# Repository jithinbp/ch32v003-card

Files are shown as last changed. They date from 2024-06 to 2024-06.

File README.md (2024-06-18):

# CH32V003 based Wedding Invites

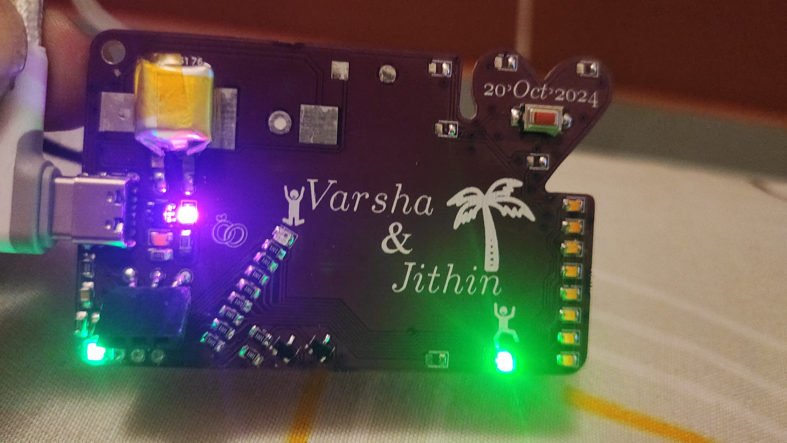
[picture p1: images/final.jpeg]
Screencast

Screencast display!

Schematics originally based on [Christmas LED ball](https://www.hackster.io/fabiosouza/christmas-ornament-based-on-ch32v003-riscv-mcu-2793db) .

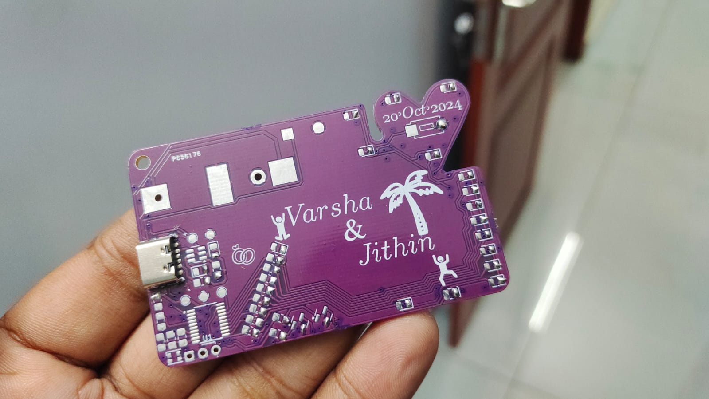
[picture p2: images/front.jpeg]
Front Render

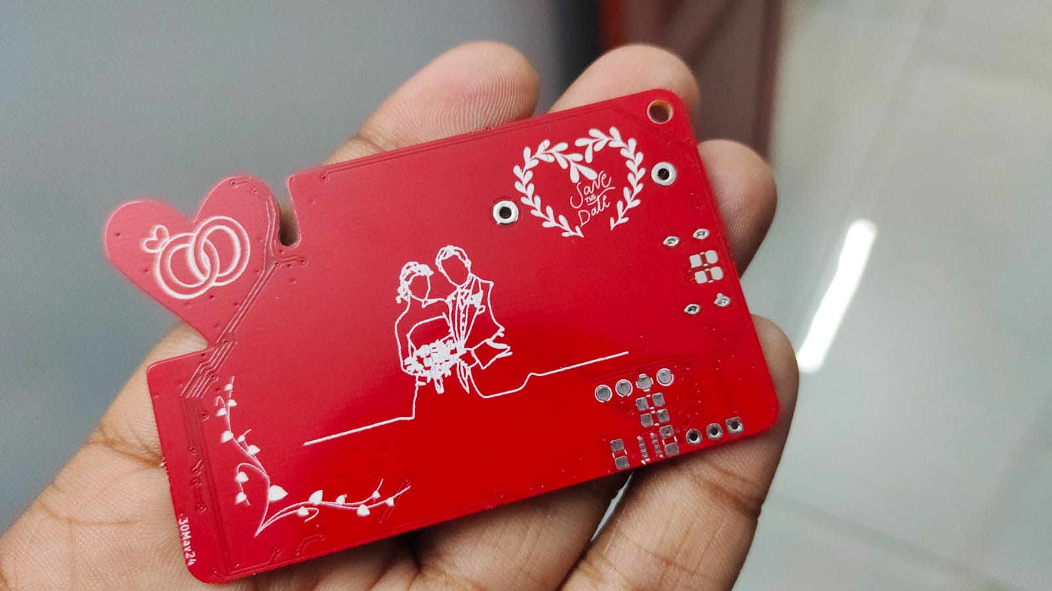
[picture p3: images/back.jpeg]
Back Render


## Features

+ USB C 6 pin connector with TP4057 for charging
+ 3.7V battery
+ CH32V003 processor
+ 14 LEDs
+ 1 RGB LED
+ IR Receiver
+ Reed switch for timing the POV display
+ footprints for BMP280 ( not tested yet )

## Software features

+ RGB LED control
+ PWM fading of LEDs
+ IR receiver via interrupt
+ Interrupt wake up and deep sleep
+ Persistence of vision display using 8 LEDs

## Author links

+ [Jithin BP](https://github.com/jithinbp/)
+ [CSpark Research](https://github.com/csparkresearch/)

## Credits

+ [Fábio Souza](https://github.com/FBSeletronica) for the CH32v003 layout for the LED christmas ball which served as a starting point for this work.
+ [CNLohr] (https://github.com/cnlohr/) for the many examples on [ch32v003fun](https://github.com/cnlohr/ch32v003fun) from where I lifted sections for H/W interrupts (for IR) , deep sleep mode and wakeup , and PWM . The datasheet was also of much help. :)

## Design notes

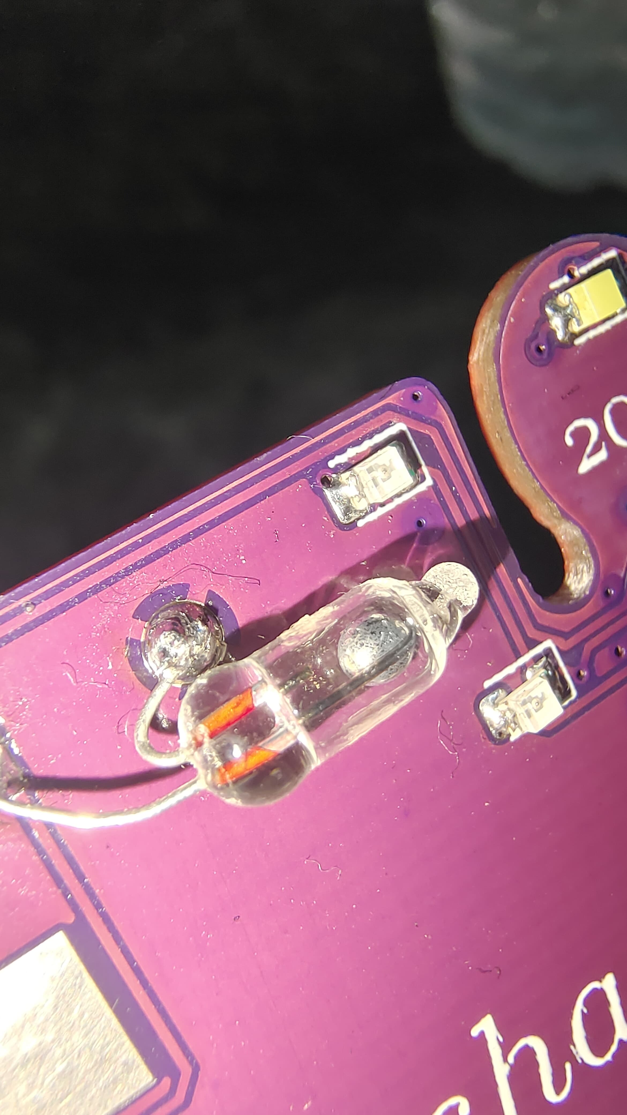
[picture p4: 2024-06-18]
images/reed.jpeg

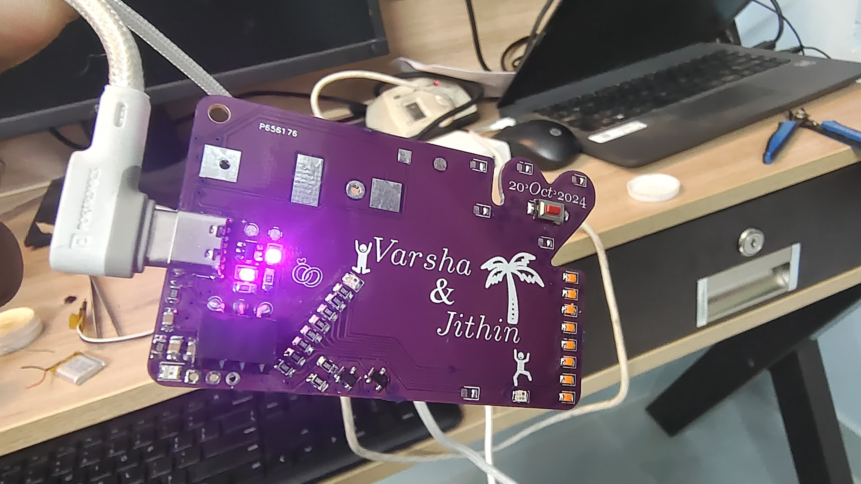
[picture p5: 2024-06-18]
images/fronon2.jpeg

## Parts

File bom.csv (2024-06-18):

Id | Designator | Footprint | Quantity | Designation | Supplier and ref
1 | D16,D11,D14,D15,D13,D10,D12,D8,D9 | LED_0805_2012Metric | 9 | PINK LED | ok
2 | D7,D17,D3,D6 | LED_0805_2012Metric | 4 | RED LED | ok
3 | D19 | LED_WS2812B-2020_PLCC4_2.0x2.0mm | 1 | WS2812B-2020 | ok
4 | U5 | SOT-23-6 | 1 | TP4057 | ok
5 | R11,R7,R10,R5,R9,R3,R6,R2,R4,R8 | R_0805_2012Metric_Pad1.20x1.40mm_HandSolder | 10 | 1K | ok
6 | R16,R15,R17,R1,R14,R12,R13 | R_0805_2012Metric_Pad1.20x1.40mm_HandSolder | 7 | 10K | ok
7 | C2 | C_0805_2012Metric_Pad1.18x1.45mm_HandSolder | 1 | 10uF | ok
8 | Q1,Q2 | SOT-23 | 2 | BC817 | ok
9 | D5,D4 | LED_0805_2012Metric | 2 | BLUE LED | ok
11 | D2,D18,D1 | LED_0805_2012Metric | 3 | GREEN LED | ok
12 | C1,C3,C5 | C_0805_2012Metric_Pad1.18x1.45mm_HandSolder | 3 | 100nF | ok
15 | P1 | USB_C_Receptacle_GCT_USB4125-xx-x_6P_TopMnt_Horizontal | 1 | USB_C_Plug_USB2.0_6pin | ok
16 | U2 | Vishay_MINICAST-3Pin | 1 | TSOP382xx | 0
17 | U1 | TSSOP-20_4.4x6.5mm_P0.65mm | 1 | CH32V003F4P6 | ok
18 | SW2 | SW_PUSH_1P1T_6x3.5mm_H4.3_APEM_MJTP1243 | 1 | SW_Push | ok
19 | U3 | Bosch_LGA-8_2x2.5mm_P0.65mm_ClockwisePinNumbering | 1 | BMP280
20 | R19,R18 | R_0805_2012Metric_Pad1.20x1.40mm_HandSolder | 2 | 5.1K

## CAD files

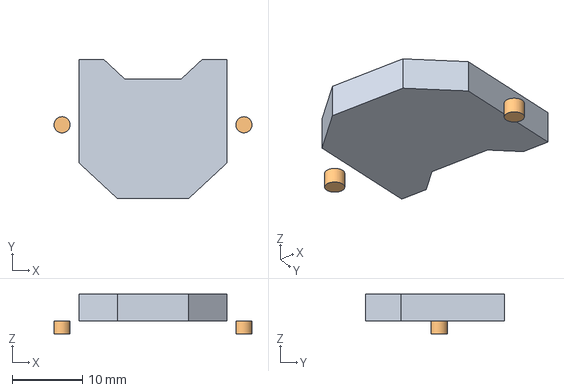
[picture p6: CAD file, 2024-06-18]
3D/BC-2001.stp
28.2 x 19.8 x 5.65 mm
Lugs x 2

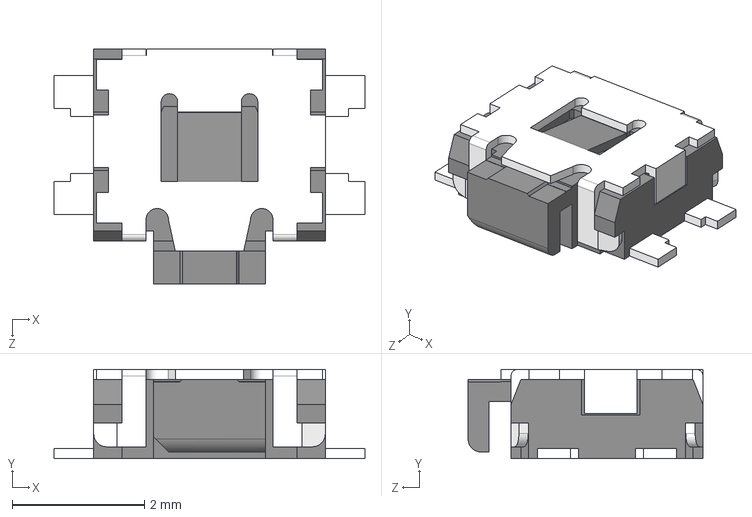
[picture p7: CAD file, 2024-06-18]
3D/EVQP7A01P.stp
4.70 x 1.35 x 3.55 mm

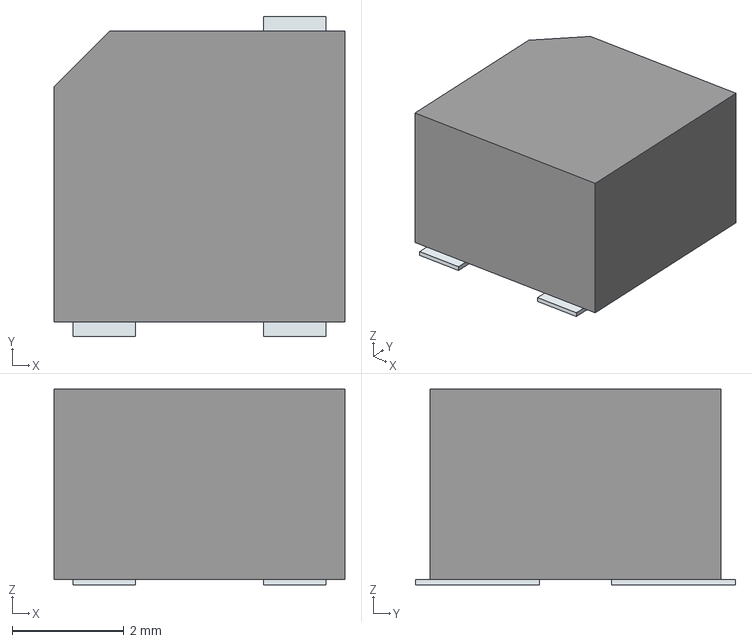
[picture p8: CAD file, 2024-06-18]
3D/MLT-5030.stp
5.20 x 5.72 x 3.50 mm
Pins

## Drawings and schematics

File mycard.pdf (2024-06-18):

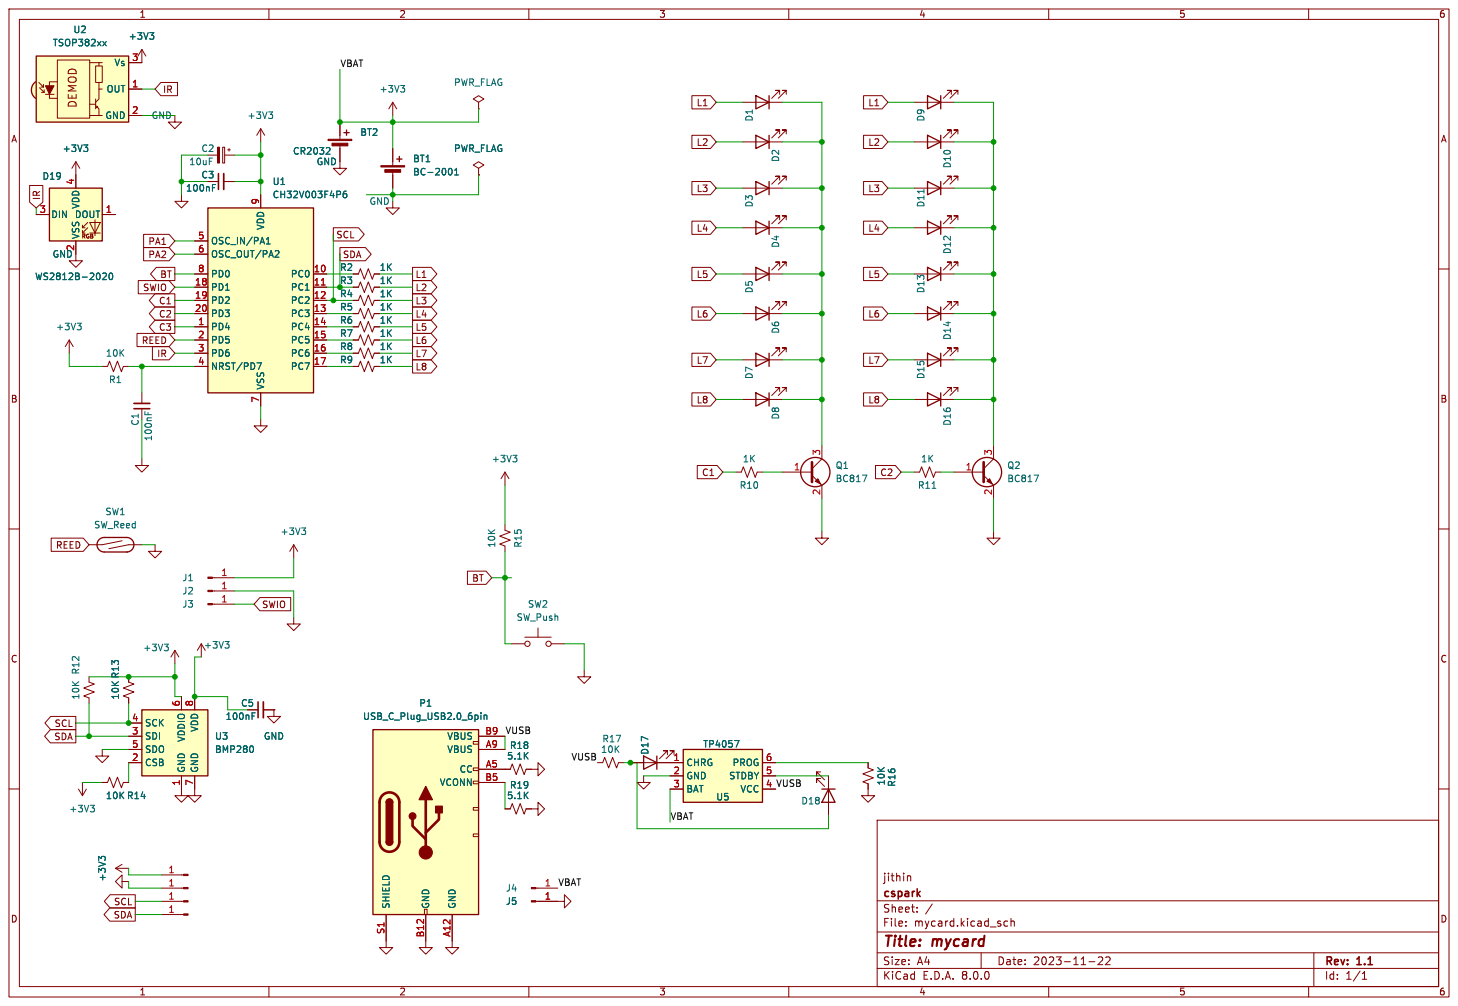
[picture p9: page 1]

File: mycard.kicad_sch Sheet: / cspark

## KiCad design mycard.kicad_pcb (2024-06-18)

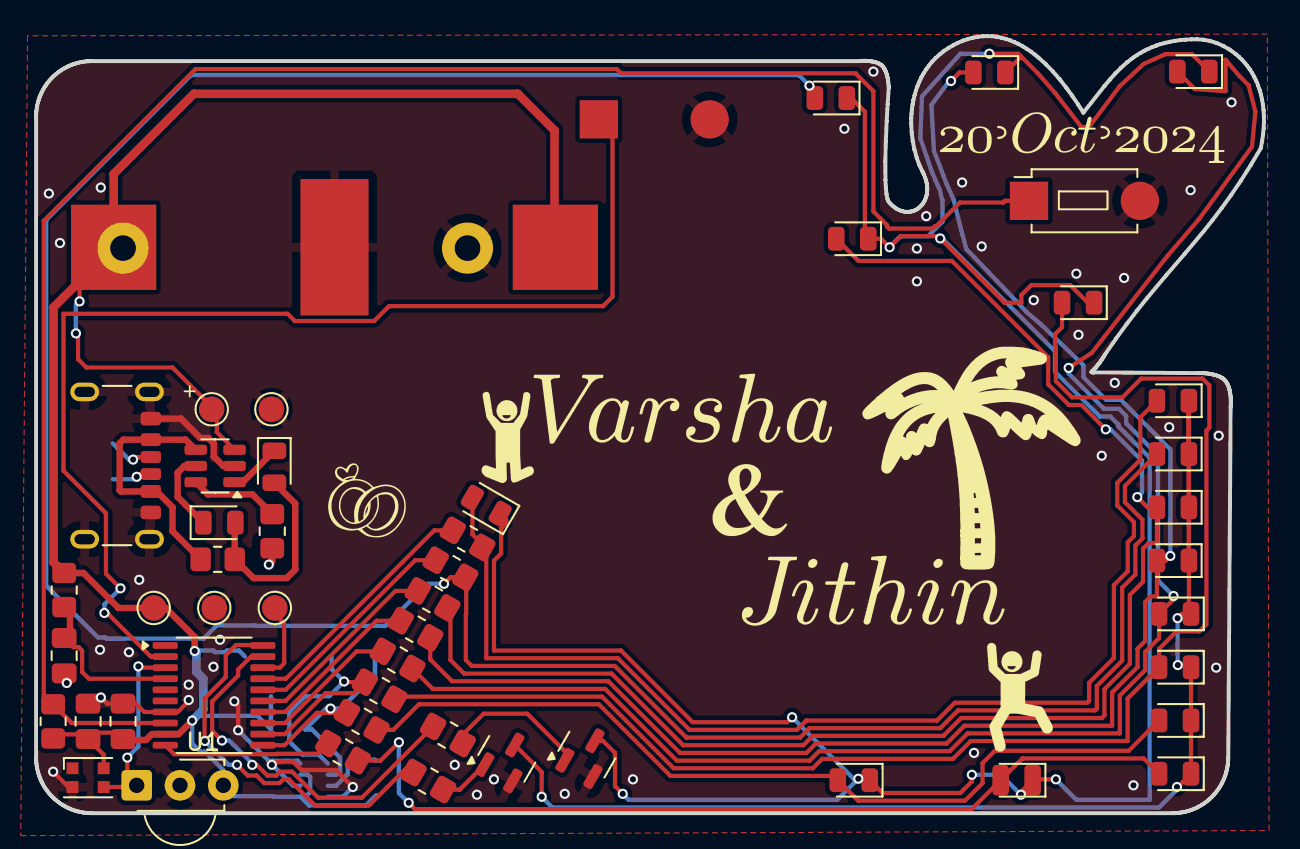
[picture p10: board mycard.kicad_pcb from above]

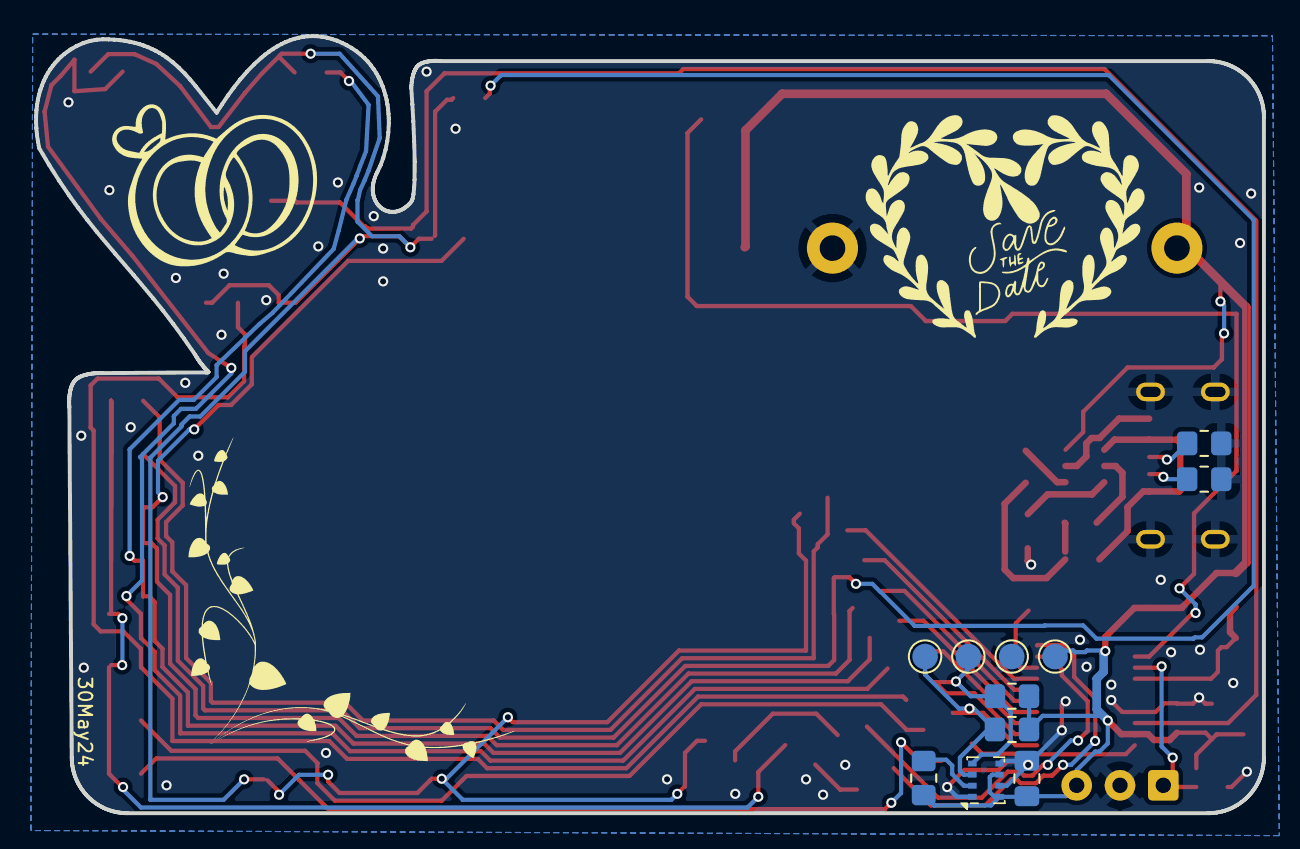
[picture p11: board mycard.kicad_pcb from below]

Board: 2 copper layers, 72.0 x 45.6 mm, 62 parts (11 on the bottom side), 37 nets.

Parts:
BT1: BC-2001; BatteryHolder_Multicomp_BC-2001_1x2032
BT2: CR2032; BatteryHolder_Keystone_3002_1x2032
C1, C3, C5: 100nF; C_0805_2012Metric_Pad1.18x1.45mm_HandSolder
C2: 10uF; C_0805_2012Metric_Pad1.18x1.45mm_HandSolder
D1, D4, D7, D10, D13: D-B080508B1-KS2; LED_0805_2012Metric
D2, D5, D8, D11, D14, D17, D18: e17-21SURC/S530-A3/TR8; LED_0805_2012Metric
D3, D6, D9, D12, D15, D16: NCD0805G1; LED_0805_2012Metric
D19: WS2812B-2020; LED_WS2812B-2020_PLCC4_2.0x2.0mm
J1, J2, J3, J4, J5: Conn_01x01_Pin; TestPoint_Pad_D1.5mm
P1: USB_C_Plug_USB2.0_6pin; USB_C_Receptacle_GCT_USB4125-xx-x_6P_TopMnt_Horizontal
Q1, Q2: BC817; SOT-23
R1, R12, R13, R14, R15, R16, R17: 10K; R_0805_2012Metric_Pad1.20x1.40mm_HandSolder
R2, R3, R4, R5, R6, R7, R8, R9, R10, R11: 1K; R_0805_2012Metric_Pad1.20x1.40mm_HandSolder
R18, R19: 5.1K; R_0805_2012Metric_Pad1.20x1.40mm_HandSolder
SW1: SW_Reed; SW_PUSH_1P1T_6x3.5mm_H4.3_APEM_MJTP1243
SW2: SW_Push; SW_PUSH_1P1T_6x3.5mm_H4.3_APEM_MJTP1243
U1: CH32V003F4P6; TSSOP-20_4.4x6.5mm_P0.65mm
U2: TSOP382xx; Vishay_MINICAST-3Pin
U3: BMP280; Bosch_LGA-8_2x2.5mm_P0.65mm_ClockwisePinNumbering
U5: TP4057; SOT-23-6
tp3v3: Conn_01x01_Pin; TestPoint_Pad_D1.5mm
tpgnd1: Conn_01x01_Pin; TestPoint_Pad_D1.5mm
tpscl1: Conn_01x01_Pin; TestPoint_Pad_D1.5mm
tpsda1: Conn_01x01_Pin; TestPoint_Pad_D1.5mm

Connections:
+3V3: BT1.1 (+), BT2.1 (+), C2.1, C3.2, C5.1, D19.4 (VDD), J1.1, J4.1, R1.1, R12.2, R13.2, R14.2, R15.2, U1.9 (VDD), U2.3 (Vs), U3.6 (VDDIO), U3.8 (VDD), U5.3 (BAT), tp3v3.1
/VUSB: P1.A9 (VBUS), P1.B9 (VBUS), R17.1, U5.4 (VCC)
BT: R15.1, SW2.1, U1.8 (PD0)
C1: R10.1, U1.19 (PD2)
C2: R11.1, U1.20 (PD3)
GND: BT1.2 (-), BT2.2 (-), C1.1, C2.2, C3.1, C5.2, D19.2 (VSS), J2.1, J5.1, P1.A12 (GND), P1.B12 (GND), P1.S1 (SHIELD), Q1.2 (E), Q2.2 (E), R16.2, R18.2, R19.2, SW1.2, SW2.2, U1.7 (VSS), U2.2 (GND), U3.1 (GND), U3.5 (SDO), U3.7 (GND), U5.2 (GND), tpgnd1.1
IR: D19.3 (DIN), U1.3 (PD6), U2.1 (OUT)
L1: D1.2 (A), D9.2 (A), R2.2
L2: D2.2 (A), D10.2 (A), R3.2
L3: D3.2 (A), D11.2 (A), R4.2
L4: D4.2 (A), D12.2 (A), R5.2
L5: D5.2 (A), D13.2 (A), R6.2
L6: D6.2 (A), D14.2 (A), R7.2
L7: D7.2 (A), D15.2 (A), R8.2
L8: D8.2 (A), D16.2 (A), R9.2
unnamed: D1.1 (K), D2.1 (K), D3.1 (K), D4.1 (K), D5.1 (K), D6.1 (K), D7.1 (K), D8.1 (K), Q1.3 (C)
unnamed: D9.1 (K), D10.1 (K), D11.1 (K), D12.1 (K), D13.1 (K), D14.1 (K), D15.1 (K), D16.1 (K), Q2.3 (C)
unnamed: D17.2 (A), D18.2 (A), R17.2
unnamed: D17.1 (K), U5.1 (CHRG)
unnamed: D18.1 (K), U5.5 (STDBY)
unnamed: P1.A5 (CC), R18.1
unnamed: P1.B5 (VCONN), R19.1
unnamed: Q1.1 (B), R10.2
unnamed: Q2.1 (B), R11.2
unnamed: C1.2, R1.2, U1.4 (NRST/PD7)
unnamed: R2.1, U1.10 (PC0)
unnamed: R5.1, U1.13 (PC3)
unnamed: R6.1, U1.14 (PC4)
unnamed: R7.1, U1.15 (PC5)
unnamed: R8.1, U1.16 (PC6)
unnamed: R9.1, U1.17 (PC7)
unnamed: R14.1, U3.2 (CSB)
unnamed: R16.1, U5.6 (PROG)
REED: SW1.1, U1.2 (PD5)
SCL: R4.1, R13.1, U1.12 (PC2), U3.4 (SCK), tpscl1.1
SDA: R3.1, R12.1, U1.11 (PC1), U3.3 (SDI), tpsda1.1
SWIO: J3.1, U1.18 (PD1)

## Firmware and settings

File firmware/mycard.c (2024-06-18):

#include "ch32v003fun.h"
#include <stdio.h>
#include "ws2812b_dma_spi_led_driver.h"


uint32_t count;
uint16_t lastnum=123;


uint8_t letters[128][6] = {
{0x00,0x00,0x00,0x00,0x00,0x00},   //   0x 0 0
{0x00,0x64,0x18,0x04,0x64,0x18},   //  0x 1 1 Left arrow
{0x00,0x3c,0x40,0x40,0x20,0x7c},   //  0x 2 2
{0x00,0x0c,0x30,0x40,0x30,0x0c},   //  0x 3 3 Right Arrow
{0x00,0x3c,0x40,0x30,0x40,0x3c},   //  0x 4 4
{0x00,0x00,0x3e,0x1c,0x08,0x00},   //  0x 5 5 Therefore
{0x00,0x04,0x1e,0x1f,0x1e,0x04},   //  0x 6 6 
{0x00,0x10,0x3c,0x7c,0x3c,0x10},   //  0x 7 7 Phone
{0x00,0x20,0x40,0x3e,0x01,0x02},   //  0x 8 8  Tick
{0x00,0x22,0x14,0x08,0x14,0x22},   //   0x 9 9
{0x00,0x00,0x38,0x28,0x38,0x00},   //   0x a 10
{0x00,0x00,0x10,0x38,0x10,0x00},   // 
 0x b 11 Music
{0x00,0x00,0x00,0x10,0x00,0x00},   //
 0x c 12
{0x00,0x08,0x78,0x08,0x00,0x00},   //   0x d 13
{0x00,0x00,0x15,0x15,0x0a,0x00},   //  0x e 14
{0x00,0x7f,0x7f,0x09,0x09,0x01},   //  0x f 15 Music 
{0x00,0x10,0x20,0x7f,0x01,0x01},   //  0x10 16
{0x00,0x04,0x04,0x00,0x01,0x1f},   //  0x11 17
{0x00,0x00,0x19,0x15,0x12,0x00},   //  0x12 18
{0x00,0x40,0x60,0x50,0x48,0x44},   //  0x13 19
{0x00,0x06,0x09,0x09,0x06,0x00},   //  0x14 20
{0x00,0x0f,0x02,0x01,0x01,0x00},   //  0x15 21 Phi 
{0x00,0x00,0x01,0x1f,0x01,0x00},   //  0x16 22
{0x00,0x44,0x44,0x4a,0x4a,0x51},   //  0x17 23
{0x00,0x14,0x74,0x1c,0x17,0x14},   //  0x18 24
{0x00,0x51,0x4a,0x4a,0x44,0x44},   //  0x19 25
{0x00,0x00,0x00,0x04,0x04,0x04},   //   0x1a 26
{0x00,0x00,0x7c,0x54,0x54,0x44},   //  0x1b 27
{0x00,0x08,0x08,0x2a,0x1c,0x08},   //  
 0x1c 28 clock
{0x00,0x7c,0x00,0x7c,0x44,0x7c},   // 
  0x1d 29 alpha 
{0x00,0x04,0x02,0x7f,0x02,0x04},   // 
  0x1e 30 
{0x00,0x10,0x20,0x7f,0x20,0x10},   //   0x1f 31
{0x00,0x00,0x00,0x00,0x00,0x00},   //   0x20 32
{0x00,0x00,0x00,0x6f,0x00,0x00},   // ! 0x21 33
{0x00,0x00,0x07,0x00,0x07,0x00},   // " 0x22 34
{0x00,0x14,0x7f,0x14,0x7f,0x14},   // // 0x23 35
{0x00,0x00,0x07,0x04,0x1e,0x00},   // $ 0x24 36
{0x00,0x23,0x13,0x08,0x64,0x62},   // % 0x25 37
{0x00,0x36,0x49,0x56,0x20,0x50},   // & 0x26 38
{0x00,0x00,0x00,0x07,0x00,0x00},   // ' 0x27 39
{0x00,0x00,0x1c,0x22,0x41,0x00},   // ( 0x28 40
{0x00,0x00,0x41,0x22,0x1c,0x00},   // ) 0x29 41
{0x00,0x14,0x08,0x3e,0x08,0x14},   // * 0x2a 42
{0x00,0x08,0x08,0x3e,0x08,0x08},   // + 0x2b 43
{0x00,0x00,0x50,0x30,0x00,0x00},   // , 0x2c 44
{0x00,0x08,0x08,0x08,0x08,0x08},   // - 0x2d 45
{0x00,0x00,0x60,0x60,0x00,0x00},   // . 0x2e 46
{0x00,0x20,0x10,0x08,0x04,0x02},   // / 0x2f 47
{0x00,0x3e,0x51,0x49,0x45,0x3e},   // 0 0x30 48
{0x00,0x00,0x42,0x7f,0x40,0x00},   // 1 0x31 49
{0x00,0x42,0x61,0x51,0x49,0x46},   // 2 0x32 50
{0x00,0x21,0x41,0x45,0x4b,0x31},   // 3 0x33 51
{0x00,0x18,0x14,0x12,0x7f,0x10},   // 4 0x34 52
{0x00,0x27,0x45,0x45,0x45,0x39},   // 5 0x35 53
{0x00,0x3c,0x4a,0x49,0x49,0x30},   // 6 0x36 54
{0x00,0x01,0x71,0x09,0x05,0x03},   // 7 0x37 55
{0x00,0x36,0x49,0x49,0x49,0x36},   // 8 0x38 56
{0x00,0x06,0x49,0x49,0x29,0x1e},   // 9 0x39 57
{0x00,0x00,0x36,0x36,0x00,0x00},   // : 0x3a 58
{0x00,0x00,0x56,0x36,0x00,0x00},   // ; 0x3b 59
{0x00,0x08,0x14,0x22,0x41,0x00},   // < 0x3c 60
{0x00,0x14,0x14,0x14,0x14,0x14},   // = 0x3d 61
{0x00,0x00,0x41,0x22,0x14,0x08},   // > 0x3e 62
{0x00,0x02,0x01,0x51,0x09,0x06},   // ? 0x3f 63
{0x00,0x3e,0x41,0x5d,0x49,0x4e},   // @ 0x40 64
{0x00,0x7e,0x09,0x09,0x09,0x7e},   // A 0x41 65
{0x00,0x7f,0x49,0x49,0x49,0x36},   // B 0x42 66
{0x00,0x3e,0x41,0x41,0x41,0x22},   // C 0x43 67
{0x00,0x7f,0x41,0x41,0x41,0x3e},   // D 0x44 68
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
};
void showchar(uint8_t);



/* some bit definitions for systick regs */
#define SYSTICK_SR_CNTIF (1<<0)
#define SYSTICK_CTLR_STE (1<<0)
#define SYSTICK_CTLR_STIE (1<<1)
#define SYSTICK_CTLR_STCLK (1<<2)
#define SYSTICK_CTLR_STRE (1<<3)
#define SYSTICK_CTLR_SWIE (1<<31)


volatile uint32_t systick_cnt;
volatile uint32_t cnts[40];
volatile uint16_t cmd=0;
volatile uint8_t bits=0, switch_wake=0;





// From https://github.com/Blakesands/CH32V003/blob/main/GD_WS2812_DRIVER.h
// Send a single bit using the GD pinwiggle protocol.
void LED_SendBit(uint8_t bit)
{
    if (bit) {
    //// Send a 1 bit
        GPIOD->BSHR |= 1 << 6; // put pin D6 high and wait for 800nS
            __asm__("nop");__asm__("nop");__asm__("nop");__asm__("nop");
            __asm__("nop");__asm__("nop");__asm__("nop");__asm__("nop");
            __asm__("nop");__asm__("nop");__asm__("nop");__asm__("nop");
            __asm__("nop");__asm__("nop");__asm__("nop");__asm__("nop");
            __asm__("nop");__asm__("nop");__asm__("nop");__asm__("nop");
            __asm__("nop");__asm__("nop");__asm__("nop");__asm__("nop");
            __asm__("nop");__asm__("nop");__asm__("nop");__asm__("nop");
            __asm__("nop");__asm__("nop");__asm__("nop");__asm__("nop");
            __asm__("nop");__asm__("nop");
        GPIOD->BCR = 1 << 6; // put pin D6 low and exit, 400nS is taken up by other functions
        return;
        }
//    else {
        // Send a 0 bit
        GPIOD->BSHR |= 1 << 6; // put pin D6 high and wait for 400nS
            __asm__("nop");__asm__("nop");__asm__("nop");__asm__("nop");
            __asm__("nop");__asm__("nop");__asm__("nop");__asm__("nop");
            __asm__("nop");__asm__("nop");__asm__("nop");__asm__("nop");
            __asm__("nop");__asm__("nop");
        GPIOD->BCR |= 1 << 6; // put pin D6 low and wait for 400nS, 400nS is taken up by other functions
            __asm__("nop");__asm__("nop");__asm__("nop");__asm__("nop");
            __asm__("nop");__asm__("nop");__asm__("nop");__asm__("nop");
            __asm__("nop");__asm__("nop");__asm__("nop");__asm__("nop");
            __asm__("nop");__asm__("nop");__asm__("nop");__asm__("nop");
            __asm__("nop");__asm__("nop");__asm__("nop");__asm__("nop");
//    }
}

// Send a single colour for a single LED
//WS2812B LEDs want 24 bits per led in the string
void LED_SendColour(uint8_t red, uint8_t green, uint8_t blue)
{
    // Send the green component first (MSB)
    for (int i = 7; i >= 0; i--) {
        LED_SendBit((green >> i) & 1);
    }
    // Send the red component next
    for (int i = 7; i >= 0; i--) {
        LED_SendBit((red >> i) & 1);
    }
    // Send the blue component last (LSB)
    for (int i = 7; i >= 0; i--) {
        LED_SendBit((blue >> i) & 1);
    }
}


void blink(){
	for(int i=0;i<2;i++){
	    GPIOC->BSHR |= 0b11111111; // set all
		Delay_Ms(500);
	    GPIOC->BCR |= 0b11111111; // clear all
		Delay_Ms(500);
	}
}

void blinkbit(uint8_t bit){
	for(int i=0;i<2;i++){
	    GPIOC->BCR |= 255; // clear all
		Delay_Ms(200);
	    GPIOC->BSHR |= 1<<bit; // set all
		Delay_Ms(200);
	}
}

void section1(){
			GPIOD->BCR |= 0b1100; GPIOD->BSHR |= 0b1000;
}
void section2(){
			GPIOD->BCR |= 0b1100; GPIOD->BSHR |= 0b0100;
}
void sectionoff(){
			GPIOC->BCR |= 0b11111111; // clear all L1-L7 as well
			GPIOD->BCR |= 0b1100;
}



void adc_init( void );
uint16_t adc_get( void );

void enableAutoWakeup();
void writeString(char * s);
void fadeRGB();

void scrollUpDown(uint8_t);
void fadeAutoRGB();

void batmon(){
	section1();
	GPIOC->BCR = 0b11111111; // clear all
	GPIOC->BSHR |= (1<<((2*adc_get()-6600)/150))-1 ; // set new
	//printf("%d\n",(2*adc_get())/1000);
	Delay_Ms(1000);
	section2();
	Delay_Ms(200);
	sectionoff();
}
void fadeheart(uint8_t times){
	sectionoff();
	// Enable GPIOC, GPIOD and TIM1
	RCC->APB2PCENR |= 	RCC_APB2Periph_TIM1;
	
	// Reset TIM1 to init all regs
	RCC->APB2PRSTR |= RCC_APB2Periph_TIM1;
	RCC->APB2PRSTR &= ~RCC_APB2Periph_TIM1;
	
	// CTLR1: default is up, events generated, edge align
	// SMCFGR: default clk input is CK_INT
	
	// Prescaler 
	TIM1->PSC = 0x0000;	
	// Auto Reload - sets period
	TIM1->ATRLR = 255;	
	// Reload immediately
	TIM1->SWEVGR |= TIM_UG;
	

	TIM1->CTLR1 |= TIM_ARPE;

	// Enable CH1 output, positive pol
	TIM1->CCER |= TIM_CC1E;
	
	// CH1 Mode is output, PWM1 (CC1S = 00, OC1M = 110)
	TIM1->CHCTLR1 |= TIM_OC1M_2 | TIM_OC1M_1 | TIM_OC1PE;
	// Set the Capture Compare Register value to 50% initially
	TIM1->CH1CVR = 1;
	// Enable TIM1 outputs
	TIM1->BDTR |= TIM_MOE;
	// Enable TIM1
	TIM1->CTLR1 |= TIM_CEN;
	funPinMode( PD2, GPIO_CFGLR_OUT_10Mhz_AF_PP );	//enable alt func
	GPIOC->BSHR |= 0b11100 ; // set new
	for(int n=0;n<times;n++){
		for(int x=1;x<255;x++){
			TIM1->CH1CVR = x;
			Delay_Ms(50);
		}
		for(int x=255;x>0;x--){
			TIM1->CH1CVR = x;
			Delay_Ms(50);
		}
	}
	// Stop TIM1
	TIM1->CTLR1 &= ~TIM_CEN;
	funPinMode( PD2, GPIO_CFGLR_OUT_10Mhz_PP );	//back to push pull
}



void EXTI7_0_IRQHandler( void ) __attribute__((interrupt));
void EXTI7_0_IRQHandler( void ) 
{
	for(int z=0;z<2;z++){
		scrollUpDown(2);
		scrollUpDown(1);
	}
	
	//fadeAutoRGB();						
	for(int z=0;z<10;z++){
		TIM2->CNT = 0;
		writeString("HELLO");
	}			
	sectionoff();
	//fadeRGB();

	EXTI->INTFR = EXTI_Line0;
}

int main()
{
	uint8_t wakeups=0;
	SystemInit();

	SetupDebugPrintf();
	SysTick->CTLR = 0;
	SysTick->CNT = 0;
	/* Enable SysTick counter, IRQ, HCLK/1 */
	SysTick->CTLR = SYSTICK_CTLR_STE | SYSTICK_CTLR_STIE |
					SYSTICK_CTLR_STCLK;
	// Enable GPIOs
	RCC->APB2PCENR = RCC_APB2Periph_GPIOD | RCC_APB2Periph_GPIOC | RCC_APB2Periph_AFIO;

	
	// Enable TIM2
	RCC->APB1PCENR |= RCC_APB1Periph_TIM2;
	// Reset TIM2 to init all regs
	RCC->APB1PRSTR |= RCC_APB1Periph_TIM2;
	RCC->APB1PRSTR &= ~RCC_APB1Periph_TIM2;
	// SMCFGR: default clk input is CK_INT
	// set TIM2 clock prescaler divider 
	TIM2->PSC = 0xFFFF;
	// Enable TIM2
	TIM2->CTLR1 |= TIM_CEN;
	

	// GPIO D3,D4 for input pin change.
	//funPinMode( PD3, GPIO_CFGLR_IN_FLOAT );
	funPinMode( PD4, GPIO_CFGLR_IN_FLOAT );

	funPinMode( PD0,  GPIO_CFGLR_IN_PUPD ); //switch

	funDigitalWrite( PA2, FUN_HIGH );
	funDigitalWrite( PD0, FUN_HIGH );

	//funPinMode( PD6,  GPIO_CFGLR_OUT_10Mhz_PP ); //rgb

	funPinMode( PC0,  GPIO_CFGLR_OUT_10Mhz_PP );
	funPinMode( PC1,  GPIO_CFGLR_OUT_10Mhz_PP );
	funPinMode( PC2,  GPIO_CFGLR_OUT_10Mhz_PP );
	funPinMode( PC3,  GPIO_CFGLR_OUT_10Mhz_PP );
	funPinMode( PC4,  GPIO_CFGLR_OUT_10Mhz_PP );
	funPinMode( PC5,  GPIO_CFGLR_OUT_10Mhz_PP );
	funPinMode( PC6,  GPIO_CFGLR_OUT_10Mhz_PP );
	funPinMode( PC7,  GPIO_CFGLR_OUT_10Mhz_PP );

	// OUTPUT TRANSISTORS
	funPinMode( PD2, GPIO_CFGLR_OUT_10Mhz_PP );	
	funPinMode( PD3, GPIO_CFGLR_OUT_10Mhz_PP );	
	funDigitalWrite( PD2, FUN_LOW );
	funDigitalWrite( PD3, FUN_LOW );



	asm volatile(
#if __GNUC__ > 10
		".option arch, +zicsr\n"
#endif
 		"addi t1, x0, 3\n"
		"csrrw x0, 0x804, t1\n"
		 : : :  "t1" );

	// Configure the D0 IO as an interrupt.
	AFIO->EXTICR = AFIO_EXTICR_EXTI0_PD;
	EXTI->INTENR = EXTI_INTENR_MR0; // Enable EXT3
	EXTI->RTENR = EXTI_FTENR_TR0;  // Falling edge trigger
	// enable interrupt
	NVIC_EnableIRQ( EXTI7_0_IRQn );
	//NVIC_DisableIRQ(EXTI7_0_IRQn);

	// select standby on power-down
	PWR->CTLR |= PWR_CTLR_PDDS;


	funPinMode( PD5,  GPIO_CFGLR_IN_PUPD ); //REED switch
	funDigitalWrite(PD5, FUN_HIGH); //pullup reed switch


	enableAutoWakeup();
	
	//adc_init(); //vdd monitoring
	while(1){

		if (wakeups%5==0)
			fadeheart(1);

		wakeups++;
		//batmon();

		NVIC_EnableIRQ( EXTI7_0_IRQn );
		// peripheral interrupt controller send to deep sleep
		sectionoff();
		PFIC->SCTLR |= (1 << 2);
		//printf("entering sleep loop \n");
		switch_wake=0; // reset switch wake flag.
		__WFE();
		//printf("\nALIVEEE\n");
		SystemInit();
		NVIC_DisableIRQ(EXTI7_0_IRQn);

	}


}


void adc_init( void )
{
	// ADCCLK = 24 MHz => RCC_ADCPRE = 0: divide by 2
	RCC->CFGR0 &= ~(0x1F<<11);
	
	// Enable  ADC
	RCC->APB2PCENR |=  RCC_APB2Periph_ADC1;
	
	// Reset the ADC to init all regs
	RCC->APB2PRSTR |= RCC_APB2Periph_ADC1;
	RCC->APB2PRSTR &= ~RCC_APB2Periph_ADC1;
	
	// Set up single conversion on chl 5(Vdd)
	ADC1->RSQR1 = 0;
	ADC1->RSQR2 = 0;
	ADC1->RSQR3 = 8;	// 0-9 for 8 ext inputs and two internals
	
	// set sampling time for chl 7
	ADC1->SAMPTR2 &= ~(ADC_SMP0<<(3*7));
	ADC1->SAMPTR2 |= 7<<(3*7);	// 0:7 => 3/9/15/30/43/57/73/241 cycles
		
	// turn on ADC and set rule group to sw trig
	ADC1->CTLR2 |= ADC_ADON | ADC_EXTSEL;
	
	// Reset calibration
	ADC1->CTLR2 |= ADC_RSTCAL;
	while(ADC1->CTLR2 & ADC_RSTCAL);
	
	// Calibrate
	ADC1->CTLR2 |= ADC_CAL;
	while(ADC1->CTLR2 & ADC_CAL);
	
	// should be ready for SW conversion now
}

/*
 * start conversion, wait and return result
 */
uint16_t adc_get( void )
{
	// start sw conversion (auto clears)
	ADC1->CTLR2 |= ADC_SWSTART;
	// wait for conversion complete
	while(!(ADC1->STATR & ADC_EOC));
	
	// get result
	return ((uint32_t)1200 * 1023 / ADC1->RDATAR); //return in mV
}


void enableAutoWakeup(){
	// enable power interface module clock
	RCC->APB1PCENR |= RCC_APB1Periph_PWR;

	// enable low speed oscillator (LSI)
	RCC->RSTSCKR |= RCC_LSION;
	while ((RCC->RSTSCKR & RCC_LSIRDY) == 0) {}

	// enable AutoWakeUp event
	EXTI->EVENR |= EXTI_Line9;
	EXTI->FTENR |= EXTI_Line9;

	// configure AWU prescaler
	PWR->AWUPSC |= PWR_AWU_Prescaler_61440;

	// configure AWU window comparison value
	PWR->AWUWR &= ~0x3f;
	PWR->AWUWR |= 63;

	// enable AWU
	PWR->AWUCSR |= (1 << 1);

}

void fadeRGB(){
	return;
		for(int y=0;y<2;y++){

			for(int x=0;x<100;x++){
				LED_SendColour(x,100-x,x);
				Delay_Ms(30);
			}
			for(int x=100;x>0;x--){
				LED_SendColour(x,100-x,x);
				Delay_Ms(30);
			}
		}
		for(int x=100;x>=0;x--){
			LED_SendColour(0,x,0);
			Delay_Ms(50);
		}

}

unsigned char reverse(unsigned char b) {
   b = (b & 0xF0) >> 4 | (b & 0x0F) << 4;
   b = (b & 0xCC) >> 2 | (b & 0x33) << 2;
   b = (b & 0xAA) >> 1 | (b & 0x55) << 1;
   return b;
}

#define POV_DEL 12
void showchar(uint8_t c){
  uint8_t x;
  for(x=0;x<6;x++)
   {
    GPIOC->BCR = 0b11111111; // clear all
    GPIOC->BSHR |= reverse( (letters[c][x]<<1)&0xFF) ; // set new
    Delay_Ms(POV_DEL);
   }
    GPIOC->BCR = 0b11111111; // clear all
}

void writeString(char * s){
	while( (((GPIOD->INDR)>>5)&1) && TIM2->CNT<1000 ); // no contact. high
	while( !(((GPIOD->INDR)>>5)&1) && TIM2->CNT<1000 ); //contact. low
	while( (((GPIOD->INDR)>>5)&1) && TIM2->CNT<1000 ); // no contact. high
    Delay_Ms(POV_DEL*2);
	GPIOD->BCR |= 0b1100; GPIOD->BSHR |= 0b1000;
	while(*s != '\0'){
		showchar(*s);
		s++;
	}
}


void scrollUpDown(uint8_t section){
		if(section==1)
			section1();
		else 
			section2();


		for(int x=0;x<8;x++)
		{
			GPIOC->BCR |= 0b11111111; // clear all
			GPIOC->BSHR |= (1<<x); // set new
			Delay_Ms(200);
		}
		for(int x=8;x>0;x--)
		{
			GPIOC->BCR |= 0b11111111; // clear all
			GPIOC->BSHR |= (1<<(x-1)); // set new
			Delay_Ms(200);
		}
		sectionoff();
}

void fadeAutoRGB(){
	section2();
	GPIOC->BSHR |= 128+1; // set new
	Delay_Ms(40000);
	sectionoff();
}
